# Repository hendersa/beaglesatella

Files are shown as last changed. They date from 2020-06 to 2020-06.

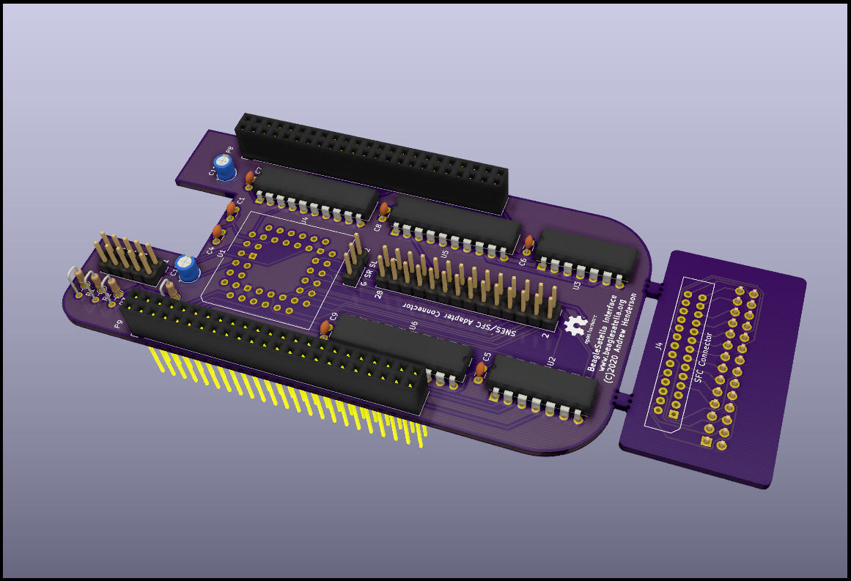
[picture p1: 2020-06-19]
images/beaglesatella_cape.jpg

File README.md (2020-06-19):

** SUMMARY **
BeagleSatella is a hardware/software solution that implements the basic 
interface functions of peripherals compatible with the Super Nintendo (SNES)
and Super Famicom (SFC) game consoles. These consoles contain a rarely-used
expansion port on their underside that was intended to interface with a variety
of hardware peripherals. Unfortunately, very few commercial peripherals were 
made available, with the most widely used being the Japan-only Satellaview 
satellite modem. 

BeagleSatella is not emulation, but an actual SNES add-on peripheral that plugs
directly into your game console. BeagleSatella uses a BeagleBone Black (BBB) 
single-board computer with a custom "cape" expansion PCB as the hardware to 
interface with the console. Firmware running on the BBB's pair of programmable
real-time units (PRUs) provides the nanosecond-scale timing required to
interface with the SNES in real-time. Additional peripheral behaviors are 
controlled using kernel drivers and userspace software running under the BBB's
Linux OS. 

** AUTHOR **
Andrew Henderson (hendersa@icculus.org): https://icculus.org/~hendersa

** DESCRIPTION **
The BeagleSatella hardware and firmware offers the following features:

- CPLD-based Hardware filtering and translation of memory-mapped I/O register
accesses from the SNES B-Bus.

- Integrated JTAG interface for easy CPLD reprogramming.

- Arbitrary range of up to 64 contiguous memory-mapped I/O registers available.

- BBB PRU usage guarantees the servicing of register read/write requests within
a 150 ns time window.

- Audio interfacing via the expansion port's stereo audio inputs.

** BUILDING **
Since BeagleSatella has both hardware and software aspects to it, this 
repository is broken down into several subdirectories:

- "cpld" contains the CUPL source code for the CPLD IC used on the cape PCB.

- "firmware" contains the PRU firmware for the BBB that communicates with the
cape PCB.

- "images" contains schematics, board renders, and other images that provide a 
preview of the system.

- "kernel" contains the kernel driver and device tree files for the BBB so that 
the BBB can communicate with the cape PCB.

- "pcb" contains the KiCad design files and gerber files for the cape PCB.

- "userspace" contains BBB userspace software for high-level control of the
whole BeagleSatella system.

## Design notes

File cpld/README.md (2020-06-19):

** SUMMARY **
The BeagleSatella hardware uses a CPLD that acts as a filter on the SNES B-Bus.
In short, there is a lot of B-Bus traffic, but BeagleSatella is only interested
in bus reads/writes that map to one of its MMIO registers. Rather than 
determine in software whether an address on the B-Bus is intended for 
BeagleSatella, the CPLD evaluates all addresses on the bus in hardware and then
only passes along the appropriate read/write control signals if the address
matches a BeagleSatella MMIO register. Because this is implemented in hardware,
the comparison can be made in ~20ns.

You shouldn't need to change the BeagleSatella CPLD design unless you are 
modifying it to filter a different range of MMIO addresses for your own 
project. You will need to program the CPLD is you are building your own
hardware from scratch and need to do the initial programming of the CPLD.

** AUTHOR **
Andrew Henderson (hendersa@icculus.org): https://icculus.org/~hendersa

** DESCRIPTION/BUILDING **
The CPLD used in BeagleSatella is an Atmel ATF1504AS in a PLCC package. The
tools and toolchain for synthesizing and programming a design for this CPLD are
Windows-based, free, and downloadable from here:

https://www.microchip.com/design-centers/fpgas-and-plds/splds-cplds/pld-design-resources 

The software tools you need are WinCUPL (for compiling the CUPL design source
code) and ATMISP (for programming the CPLD via JTAG).  You’ll also need a 
hardware JTAG programmer that uses a JTAG-A 10-pin connector. I use the 
Microchip ATDH1150USB USB ISP cable, which costs rough 60USD. The workflow is
as follows:

1. Using WinCUPL, open the file BEAGLESATELLA.pld. This is the main source 
file. Click the “Device Dependent Compile” button on the WinCUPL GUI to compile
this design and generate a variety of intermediary files. The two generated 
files of interest are the BEAGLESATELLA.jed JEDEC file (the file to be 
programmed to the CPLD) and the BEAGLESATELLA.fit file (the pinout and logic 
summary).

2. If you are serious about CPLD development and want to really experiment with
BeagleSatella’s CPLD source, you should have a CPLD development kit:

- ATF15XX-DK3-U CPLD development kit, with JTAG USB cable (~160USD)
- ATF15XXDK3-SAJ44 44-pin PLCC adapter for the devkit (~40USD)

If you are only interested in tweaking the CPLD design and reprogramming your
CPLD, BeagleSatella supports in-system programming (ISP). In short, you can 
connect a JTAG cable that supports JTAG-A (10-pin) to the BeagleSatella 
(connector J3) and program the CPLD in-place. For this, you’ll only need a JTAG
USB cable:

- ATDH1150USB USB JTAG cable (~60USD)

This USB JTAG cable is included in the ATF15XX development kit. The kit's docs
say that it comes with a parallel port-based JTAG cable, but this isn't the
case. Once you have the appropriate equipment, it is time to start programming
the CPLD.

3. Ensure that you have the CPLD powered up and is ready to be programmed. When
using the dev kit, the programming process is:

A. Power down the dev kit
B. Change the “VccIO Selector” jumper to “5V(AS)”
C. CAREFULLY insert the 44-pin PLCC into the PLCC adapter (the adapter pins 
bend very easily)
D. Power up the dev kit
E. Program the CPLD using ATMISP
F. Power down the dev kit
G. Power down your BBB
G. Remove the CPLD from the dev kit and place it into the U1 socket on the
BeagleSatella (the “dot” for pin 1 should face the BBB’s ethernet jack)
H. Power up your BBB

When programming the CPLD using the BeagleSatella board, the programming
process is:

A. Power up your BBB
B. Connect the USB JTAG cable to connector J3 of the BeagleSatella
C. Program the CPLD using ATMISP
D. Disconnect the USB JTAG cable from connector J3 

4. Now that you have the JEDEC file, use ATMISP to program the CPLD with the
compiled design. Connect to the USB JTAG to both the system with the CPLD 
(either BeagleSatella or the CPLD dev kit) and your desktop PC. Read the 
ATMISP documentation for the details, but the workflow is:

A. Add the ATF1504AS to the JTAG scan chain (Edit → Add New Device)
B. “Erase” the CPLD
C. “Program/Verify” the CPLD using the JEDEC file “BEAGLESATELLA.jed”

Additional Notes:

- WinCUPL can’t handle spaces in filenames, so don’t try to build your project
from some directory named something like “c:\my stuff\beaglesatella”. It will
just fail without an explanation.
- WinCUPL crashes a lot, so save often!
- When making design changes, WinCUPL can silently fail at an intermediary 
stage of the compilation process. It doesn’t remove any existing output files
when it does this, so it may look like your compile has completed successfully.
I highly recommend you manually delete all files except the .pld and .si files
before you rebuild the project.
- If WinCUPL is silently failing to build your project, and you've gotten far
enough to generate the BEAGLESATELLA.tt2 file, try running the included 
"build.bat" file. This executes the fitter program for the ATF1504 CPLD and
dumps out build errors that the WinCUPL GUI never shows you.

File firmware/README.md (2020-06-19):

** SUMMARY ** 
This directory contains both the current in-development PRU firmware and 
a test program to load the firmware onto the PRUs using the UIO driver.

** AUTHOR **
Andrew Henderson (hendersa@icculus.org): https://icculus.org/~hendersa

** DESCRIPTION **
The key files in this repository are:

prussdrv/*   : The Texas Instruments prussdrv driver library
pru.c        : Convenience wrapper functions around the prussdrv interface
test.c       : Starts execution of PRU firmware
pru0.p       : PRU0 firmware code (PRU assembly)
pru1.p       : PRU1 firmware code (PRU assembly)

** BUILDING **
To build the *.p files, you'll need the PASM tool:

$ git clone https://github.com/beagleboard/am335x_pru_package
$ cd am335x_pru_package/pru_sw/utils/pasm_source
$ ./linuxbuild
$ sudo cp ../pasm /usr/local/bin

Once PASM is installed, you can build the software (on your BBB) via make:

$ make

Then, load the firmware onto the PRUs and start them running:

$ sudo ./test

Since the PRU code uses every available PRU signal, the BeagleSatella device
tree overlay in the "kernel" directory must be used prior to running the PRU
code. This also means that the eMMC and HDMI overlays must be disabled in your
uEnv.txt file.

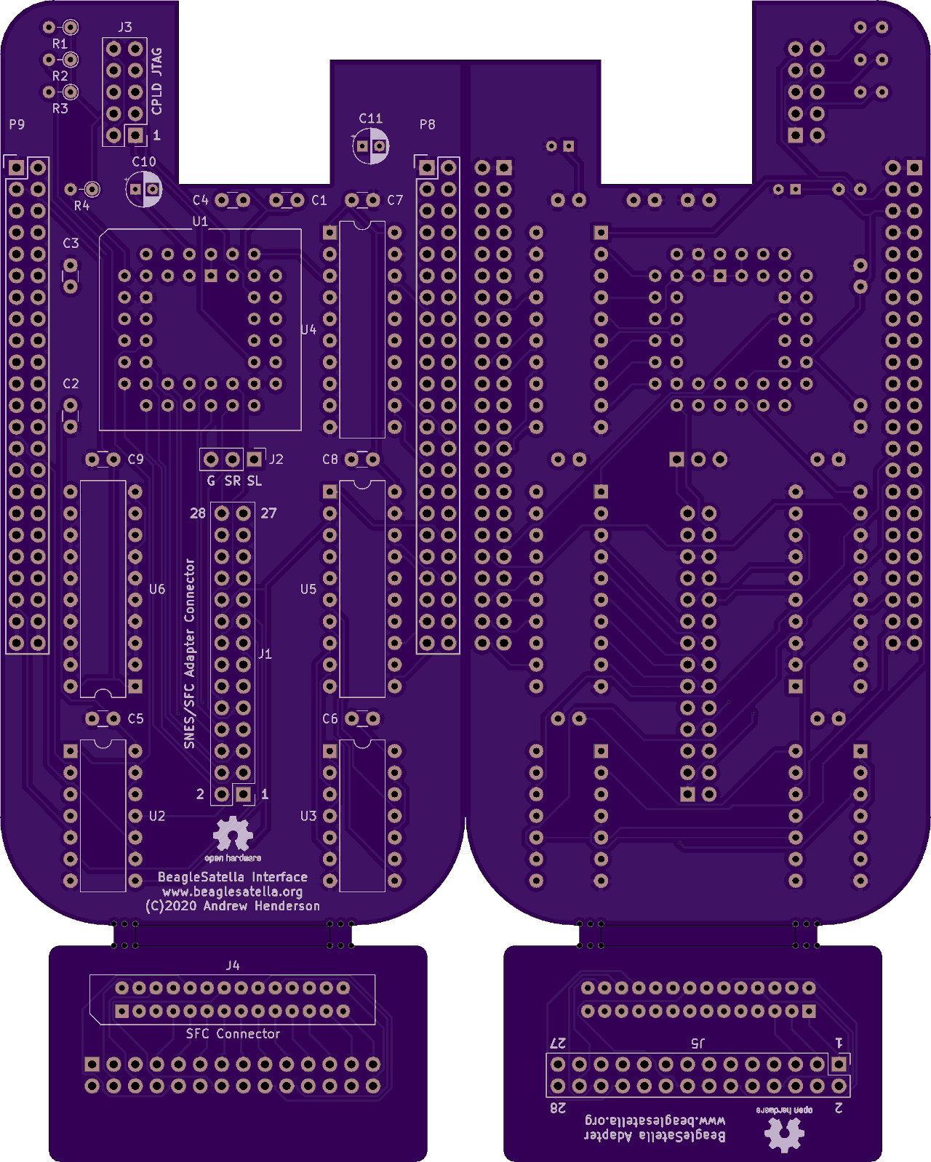
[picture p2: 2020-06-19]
images/PCB_preview.jpg

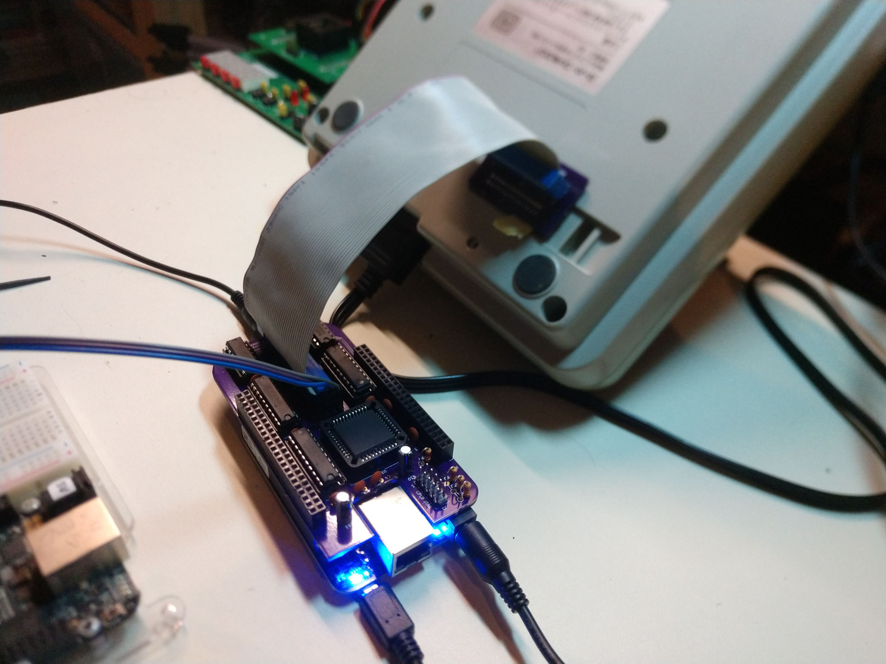
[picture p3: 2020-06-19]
images/in_use.jpg

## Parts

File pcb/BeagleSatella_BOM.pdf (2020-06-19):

# Bill Of Materials For BeagleSatella Interface Cape Board

Qty | Value | Parts | Package | Digikey Part | Unit Price | Extended Price | Description | Additional Notes
2 1 1 1 4 9 2 1 1 2 3 2 | N/A N/A N/A N/A 10k 0.1uF 10uF N/A N/A N/A N/A N/A | J1, J5 J2 J3 J4 R1-R4 C1-C9 C10-C11 N/A U1 U2, U3 U4-U6 P8, P9 | N/A N/A N/A N/A Axial ¼ Watt Ceramic Radial Aluminum Radial 44-pin PLCC 44-pin PLCC 14-Pin DIP 20-Pin DIP N/A | S2021EC-14-ND S1012EC-03-ND 1849-1002-ND 612-MEC2-40-01-L-TH1-WT-ND 10KQBK-ND BC5137-ND P15786CT-ND 123-A-CCS044-Z-T-ND ATF1504AS-10JU44-ND 296-4655-5-ND 296-8503-5-ND S2012EC-23-ND | $0.79 $0.09 $0.16 $0.02 $0.10 $0.16 $0.24 $1.17 $3.20 $0.40 $0.59 $0.79 | $1.58 $0.09 $0.16 $0.02 $0.40 $1.47 $0.48 $1.17 $3.20 $0.80 $1.77 $1.58 | Connection Header Vertical 28 Pos 2.54mm Pitch Connection Header Vertical 3 Pos 2.54mm Pitch Connection Header Vertical 10 Pos 2.54mm Pitch Connector Card Edge 2mm Vertical Resistor 10K Ohm 1/4W 5% Axial Capacitor Ceramic 0.1uF 50V X7R Radial Capacitor Aluminum 10uF 20% 16V Radial Connector Socket PLCC 44 Pos Tin Atmel ATF1504AS 10ns CPLD SN74AHCT125N IC Buffer Non-Interting 5.5V SN74LVC245AN IC TXRX Non-Inverting 3.6V Connection Header Vertical 46 Pos 2.54mm Pitch | Must be cut to 2x18, provides 2 connectors Priced at per-unit cost of 10-unit price break Socket for U1 Beaglebone cape header, 2x23 pins
Total: | 12.715

# Alternative Components

Qty | Value | Parts | Package | Digikey Part | Unit Price | Extended Price | Description | Additional Notes
1 | N/A | P8,P9 | N/A | 1528-1365-ND | $4.95 | $4.95 | Header Stack BeagleBone (2 piece) | Pair of Beaglebone cape headers (pass-through)

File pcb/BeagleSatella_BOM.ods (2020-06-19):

Bill Of Materials For BeagleSatella Interface Cape Board
Qty | Value | Parts | Package | Digikey Part | Unit Price | Extended Price | Description | Additional Notes
2 | N/A | J1, J5 | N/A | S2021EC-14-ND | $0.79 | $1.58 | Connection Header Vertical 28 Pos 2.54mm Pitch
1 | N/A | J2 | N/A | S1012EC-03-ND | $0.09 | $0.09 | Connection Header Vertical 3 Pos 2.54mm Pitch
1 | N/A | J3 | N/A | 1849-1002-ND | $0.16 | $0.16 | Connection Header Vertical 10 Pos 2.54mm Pitch
1 | N/A | J4 | N/A | 612-MEC2-40-01-L-TH1-WT-ND | $0.02 | $0.02 | Connector Card Edge 2mm Vertical | Must be cut to 2x18, provides 2 connectors
4 | 10k | R1-R4 | Axial ¼ Watt | 10KQBK-ND | $0.10 | $0.40 | Resistor 10K Ohm 1/4W 5% Axial
9 | 0.1uF | C1-C9 | Ceramic Radial | BC5137-ND | $0.16 | $1.47 | Capacitor Ceramic 0.1uF 50V X7R Radial | Priced at per-unit cost of 10-unit price break
2 | 10uF | C10-C11 | Aluminum Radial | P15786CT-ND | $0.24 | $0.48 | Capacitor Aluminum 10uF 20% 16V Radial
1 | N/A | N/A | 44-pin PLCC | 123-A-CCS044-Z-T-ND | $1.17 | $1.17 | Connector Socket PLCC 44 Pos Tin | Socket for U1
1 | N/A | U1 | 44-pin PLCC | ATF1504AS-10JU44-ND | $3.20 | $3.20 | Atmel ATF1504AS 10ns CPLD
2 | N/A | U2, U3 | 14-Pin DIP | 296-4655-5-ND | $0.40 | $0.80 | SN74AHCT125N IC Buffer Non-Interting 5.5V
3 | N/A | U4-U6 | 20-Pin DIP | 296-8503-5-ND | $0.59 | $1.77 | SN74LVC245AN IC TXRX Non-Inverting 3.6V
2 | N/A | P8, P9 | N/A | S2012EC-23-ND | $0.79 | $1.58 | Connection Header Vertical 46 Pos 2.54mm Pitch | Beaglebone cape header, 2x23 pins
 |  |  |  | Total: |  | 12.715
Alternative Components
Qty | Value | Parts | Package | Digikey Part | Unit Price | Extended Price | Description | Additional Notes
1 | N/A | P8,P9 | N/A | 1528-1365-ND | $4.95 | $4.95 | Header Stack BeagleBone (2 piece) | Pair of Beaglebone cape headers (pass-through)

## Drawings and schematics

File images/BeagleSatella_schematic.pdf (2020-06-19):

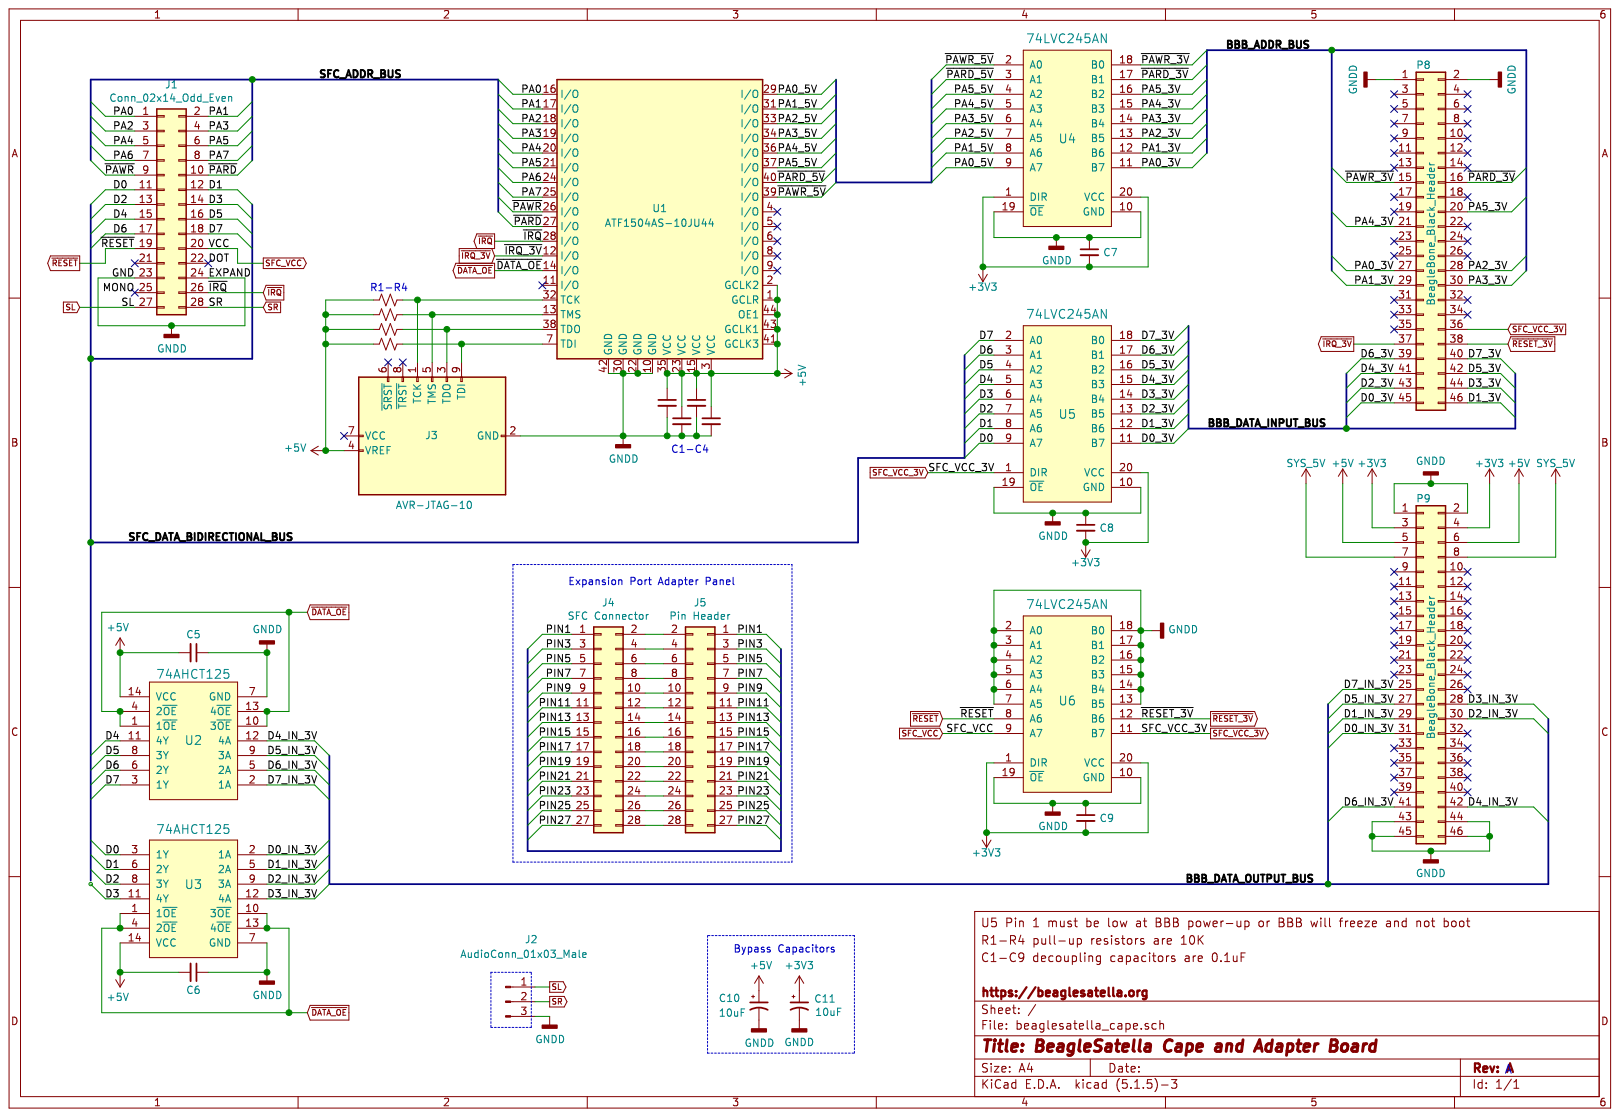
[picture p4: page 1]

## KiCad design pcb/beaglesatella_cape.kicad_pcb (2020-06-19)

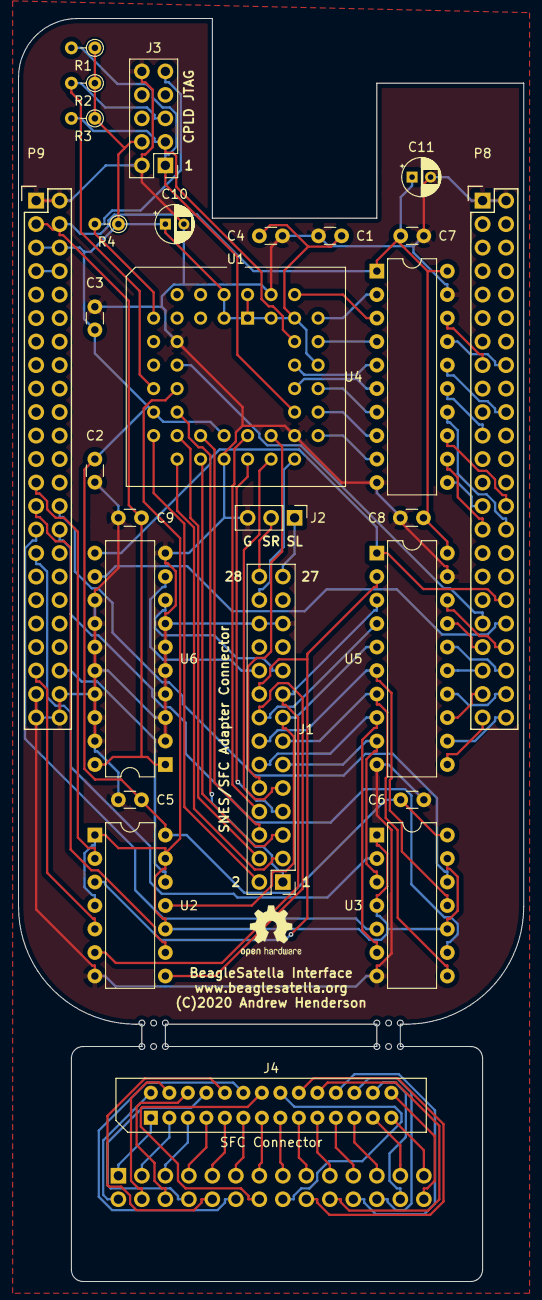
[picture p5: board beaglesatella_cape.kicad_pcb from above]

Board: 2 copper layers, 54.6 x 136.5 mm, 40 parts (1 on the bottom side), 95 nets.

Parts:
 : Panel_Tab_Hole
 #2,  #3,  #4,  #5,  #6,  #7,  #8,  #9,  #10,  #11,  #12: Panel_Tab_Hole
C1, C2, C3, C4, C5, C6, C7, C8, C9: 0.1uF; C_Disc_D3.0mm_W1.6mm_P2.50mm
C10, C11: 10uF; CP_Radial_D4.0mm_P2.00mm
J1: Conn_02x14_Odd_Even; PinHeader_2x14_P2.54mm_Vertical
J2: AudioConn_01x03_Male; PinHeader_1x03_P2.54mm_Vertical
J3: AVR-JTAG-10; PinHeader_2x05_P2.54mm_Vertical
J4: SFC Connector; Samtec_MECF-40-01-L-DV-WT_2x40_P1.27mm_Polarized_Socket_Hor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
J5: Pin Header; PinHeader_2x14_P2.54mm_Vertical
P8, P9: BeagleBone_Black_Header; Socket_BeagleBone_Black
R1, R2, R3, R4: 10K; R_Axial_DIN0204_L3.6mm_D1.6mm_P2.54mm_Vertical
U1: ATF1504AS-10JU44; PLCC-44_THT-Socket
U2, U3: 74AHCT125; DIP-14_W7.62mm
U4, U5, U6: 74LVC245AN; DIP-20_W7.62mm

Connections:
+3V3: C7.2, C8.2, C9.2, C11.1, P9.3, P9.4, U4.1, U4.20, U5.20, U6.1, U6.20
+5V: C1.1, C2.1, C3.1, C4.1, C5.2, C6.2, C10.1, J3.4, P9.5, P9.6, R1.1, R2.1, R3.1, R4.1, U1.1, U1.2, U1.3, U1.15, U1.23, U1.35, U1.41, U1.43, U1.44, U2.14, U3.14
/D0: J1.11, U3.3, U5.9
/D0_3V: P8.45, U5.11
/D0_IN_3V: P9.31, U3.2
/D1: J1.12, U3.6, U5.8
/D1_3V: P8.46, U5.12
/D1_IN_3V: P9.29, U3.5
/D2: J1.13, U3.8, U5.7
/D2_3V: P8.43, U5.13
/D2_IN_3V: P9.30, U3.9
/D3: J1.14, U3.11, U5.6
/D3_3V: P8.44, U5.14
/D3_IN_3V: P9.28, U3.12
/D4: J1.15, U2.11, U5.5
/D4_3V: P8.41, U5.15
/D4_IN_3V: P9.42, U2.12
/D5: J1.16, U2.8, U5.4
/D5_3V: P8.42, U5.16
/D5_IN_3V: P9.27, U2.9
/D6: J1.17, U2.6, U5.3
/D6_3V: P8.39, U5.17
/D6_IN_3V: P9.41, U2.5
/D7: J1.18, U2.3, U5.2
/D7_3V: P8.40, U5.18
/D7_IN_3V: P9.25, U2.2
/PA0: J1.1, U1.16
/PA0_3V: P8.27, U4.11
/PA0_5V: U1.29, U4.9
/PA1: J1.2, U1.17
/PA1_3V: P8.29, U4.12
/PA1_5V: U1.31, U4.8
/PA2: J1.3, U1.18
/PA2_3V: P8.28, U4.13
/PA2_5V: U1.33, U4.7
/PA3: J1.4, U1.19
/PA3_3V: P8.30, U4.14
/PA3_5V: U1.34, U4.6
/PA4: J1.5, U1.20
/PA4_3V: P8.21, U4.15
/PA4_5V: U1.36, U4.5
/PA5: J1.6, U1.21
/PA5_3V: P8.20, U4.16
/PA5_5V: U1.37, U4.4
/PA6: J1.7, U1.24
/PA7: J1.8, U1.25
/PIN1: J4.1, J5.1
/PIN3: J4.3, J5.3
/PIN5: J4.5, J5.5
/PIN7: J4.7, J5.7
/PIN9: J4.9, J5.9
/PIN11: J4.11, J5.11
/PIN13: J4.13, J5.13
/PIN15: J4.15, J5.15
/PIN17: J4.17, J5.17
/PIN19: J4.19, J5.19
/PIN21: J4.21, J5.21
/PIN23: J4.23, J5.23
/PIN25: J4.25, J5.25
/PIN27: J4.27, J5.27
/~PARD: J1.10, U1.27
/~PARD_3V: P8.16, U4.17
/~PARD_5V: U1.40, U4.3
/~PAWR: J1.9, U1.26
/~PAWR_3V: P8.15, U4.18
/~PAWR_5V: U1.39, U4.2
GNDD: C1.2, C2.2, C3.2, C4.2, C5.1, C6.1, C7.1, C8.1, C9.1, C10.2, C11.2, J1.23, J1.24, J2.3, J3.2, J3.10, P8.1, P8.2, P9.1, P9.2, P9.43, P9.44, P9.45, P9.46, U1.10, U1.22, U1.30, U1.42, U2.7, U3.7, U4.10, U4.19, U5.10, U5.19, U6.2, U6.3, U6.4, U6.5, U6.6, U6.7, U6.10, U6.13, U6.14, U6.15, U6.16, U6.17, U6.18, U6.19
unnamed: J3.1, R1.2, U1.32
unnamed: J3.3, R3.2, U1.38
unnamed: J3.5, R2.2, U1.13
unnamed: J3.9, R4.2, U1.7
unnamed: J4.2, J5.2
unnamed: J4.4, J5.4
unnamed: J4.6, J5.6
unnamed: J4.8, J5.8
unnamed: J4.10, J5.10
unnamed: J4.12, J5.12
unnamed: J4.14, J5.14
unnamed: J4.16, J5.16
unnamed: J4.18, J5.18
unnamed: J4.20, J5.20
unnamed: J4.22, J5.22
unnamed: J4.24, J5.24
unnamed: J4.26, J5.26
unnamed: J4.28, J5.28
SFC_VCC: J1.20, U6.9
SFC_VCC_3V: P8.36, U5.1, U6.11
SL: J1.27, J2.1
SR: J1.28, J2.2
SYS_5V: P9.7, P9.8
~DATA_OE: U1.14, U2.1, U2.4, U2.10, U2.13, U3.1, U3.4, U3.10, U3.13
~IRQ: J1.26, U1.28
~IRQ_3V: P8.37, U1.12
~RESET: J1.19, U6.8
~RESET_3V: P8.38, U6.12

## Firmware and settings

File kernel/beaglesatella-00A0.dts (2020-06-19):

/*
 * Copyright (C) 2020 Andrew Henderson (hendersa@icculus.org)
 *
 * This program is free software; you can redistribute it and/or modify
 * it under the terms of the GNU General Public License version 2 as
 * published by the Free Software Foundation.
 */
/dts-v1/;
/plugin/;

/ {
	compatible = "ti,beaglebone-black";

	/* identification */
	part-number = "BEAGLESATELLA";
	version = "00A0";

	fragment@0 {
		target-path="/";
		__overlay__ {
			pru-beaglesatella {
				compatible = "beaglesatella,beaglesatella";
				pruss = <&pruss>;
				interrupt-parent = <&pruss_intc>;
				interrupts = <22>, <23>, <24>;
				interrupt-names = "from_bl_1", "to_bl", "from_bl_2";
			};
		};
	};

	/*
	 * Free up the pins used by the cape from the pinmux helpers.
	 */
	fragment@1 {
		target = <&ocp>;
		__overlay__ {

			/* PRU0 R30 DataOut[7:0] pins (Mode 5, Output) */
			P9_31_pinmux { status = "disabled"; };  /* P9_31:   R30[0] -> DataOut[0] */
			P9_29_pinmux { status = "disabled"; };  /* P9_29:   R30[1] -> DataOut[1] */ 
			P9_30_pinmux { status = "disabled"; };  /* P9_30:   R30[2] -> DataOut[2] */
			P9_28_pinmux { status = "disabled"; };  /* P9_28:   R30[3] -> DataOut[3] */
			P9_92_pinmux { status = "disabled"; };	/* P9_42.1: R30[4] -> DataOut[4] */
			P9_27_pinmux { status = "disabled"; };	/* P9_27:   R30[5] -> DataOut[5] */
			P9_91_pinmux { status = "disabled"; };  /* P9_41.1: R30[6] -> DataOut[6] */
			P9_25_pinmux { status = "disabled"; };	/* P9_25:   R30[7] -> DataOut[7] */

			/* Eliminate P9_41/42 conflicts (Mode 7, Input) */
			P9_41_pinmux { status = "disabled"; };
			P9_42_pinmux { status = "disabled"; };

			/* PRU0 R31 PARD input pin (Mode 6, Input) */
			P8_16_pinmux { status = "disabled"; };	/* P8_16: PARD -> R31[14] */

			/* PRU0 R31 PAWR input pin (Mode 6, Input) */
			P8_15_pinmux { status = "disabled"; };	/* P8_15: PAWR -> R31[15] */

			/* PRU1 R31 DataIn[7:0] pins (Mode 6, Input) */
			P8_45_pinmux { status = "disabled"; };	/* P8_45: DataIn[0] -> R31[0] */
			P8_46_pinmux { status = "disabled"; };	/* P8_46: DataIn[1] -> R31[1] */
			P8_43_pinmux { status = "disabled"; };	/* P8_43: DataIn[2] -> R31[2] */
			P8_44_pinmux { status = "disabled"; };	/* P8_44: DataIn[3] -> R31[3] */
			P8_41_pinmux { status = "disabled"; };	/* P8_41: DataIn[4] -> R31[4] */
			P8_42_pinmux { status = "disabled"; };	/* P8_42: DataIn[5] -> R31[5] */
			P8_39_pinmux { status = "disabled"; };	/* P8_39: DataIn[6] -> R31[6] */
			P8_40_pinmux { status = "disabled"; };  /* P8_40: DataIn[7] -> R31[7] */

			/* PRU1 R31 AddrIn[5:0] pins (Mode 6, Input) */
			P8_27_pinmux { status = "disabled"; };  /* P8_27: AddrIn[0] -> R31[8] */
			P8_29_pinmux { status = "disabled"; };  /* P8_29: AddrIn[1] -> R31[9] */
			P8_28_pinmux { status = "disabled"; };  /* P8_28: AddrIn[2] -> R31[10] */
			P8_30_pinmux { status = "disabled"; };  /* P8_30: AddrIn[3] -> R31[11] */
			P8_21_pinmux { status = "disabled"; };  /* P8_21: AddrIn[4] -> R31[12] */
			P8_20_pinmux { status = "disabled"; };	/* P8_20: AddrIn[5] -> R31[13] */

			/* KERNEL GPIO /RESET pin (Mode 7, Input) */
			P8_38_pinmux { status = "disabled"; };  /* P8_38: /RESET -> GPIO2[15] */

			/* KERNEL GPIO /IRQ pin (Mode 7, Output) */
			P8_37_pinmux { status = "disabled"; };  /* P8_37: GPIO2[14] -> /IRQ */

			/* KERNEL GPIO VCC pin (Mode 7, Input) */
			P8_36_pinmux { status = "disabled"; };	/* P8_36: VCC -> GPIO2[16] */

			beaglesatella_helper: helper {
				compatible = "bone-pinmux-helper";
				pinctrl-names = "default";
				pinctrl-0 = <&beaglesatella_pins>;
				status = "okay";
			};
		};
	};

	fragment@2 {
		target = <&am33xx_pinmux>;
		__overlay__ {
			beaglesatella_pins: beaglesatella_pins {
				pinctrl-single,pins = <
					/* PRU0 R30 DataOut_3V[7:0] pins (Mode 5: PRU Output) */
					0x190 0x25	/* P9_31 */
					0x194 0x25	/* P9_29 */
					0x198 0x25	/* P9_30 */
					0x19c 0x25	/* P9_28 */
					0x1a0 0x25	/* P9_42.1 */
					0x1a4 0x25	/* P9_27 */
					0x1a8 0x25	/* P9_41.1 */
					0x1ac 0x25	/* P9_25 */

					/* Eliminate P9_41/42 conflicts (Mode 7: GPIO, Input, Disabled Pull-Up/Down, Fast Slew: 0x2F) */
					0x1b4 0x2F	/* P9_41 */
					0x164 0x2F	/* P9_42 */

					/* PRU0 R31 /PARD_3V pin (Mode 6: PRU Input) */
					0x038 0x26	/* P8_16 */

					/* PRU0 R31 /PAWR_3V pin (Mode 6: PRU Input) */
					0x03c 0x26	/* P8_15 */

					/* PRU1 R31 DataIn_3V[7:0] pins (Mode 6: PRU Input) */
					0x0a0 0x26	/* P8_45 */
					0x0a4 0x26	/* P8_46 */
					0x0a8 0x26	/* P8_43 */
					0x0ac 0x26	/* P8_44 */
					0x0b0 0x26	/* P8_41 */
					0x0b4 0x26	/* P8_42 */
					0x0b8 0x26	/* P8_39 */
					0x0bc 0x26	/* P8_40 */

					/* PRU1 R31 AddrIn[5:0] pins (Mode 6: PRU Input) */
					0x0e0 0x26	/* P8_27 */
					0x0e4 0x26	/* P8_29 */
					0x0e8 0x26	/* P8_28 */
					0x0ec 0x26	/* P8_30 */
					0x080 0x26	/* P8_21 */
					0x084 0x26	/* P8_20 */

					/* KERNEL GPIO /RESET_3V pin (Mode 7: GPIO, Input, Pull Up, Fast Slew: 0x37) */
					0x0c4 0x37	/* P8_38 */ 

					/* KERNEL GPIO /IRQ_3V pin (Mode 7: GPIO, Output, Disabled Pull Up/Down, Fast Slew: 0x0F) */
					0x0c0 0x0F	/* P8_37 */ 

					/* KERNEL GPIO SFC_VCC_3V pin (Mode 7: GPIO, Input, Pull Down, Fast Slew: 0x27) */
					0x0c8 0x27	/* P8_36 */

				>;
			};
		};
	};

};

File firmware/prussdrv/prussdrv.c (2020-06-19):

/*
 * prussdrv.c
 *
 * User space driver for PRUSS
 *
 * Copyright (C) 2012 Texas Instruments Incorporated - http://www.ti.com/
 *
 *
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
 *    Redistributions of source code must retain the above copyright
 *    notice, this list of conditions and the following disclaimer.
 *
 *    Redistributions in binary form must reproduce the above copyright
 *    notice, this list of conditions and the following disclaimer in the
 *    documentation and/or other materials provided with the
 *    distribution.
 *
 *    Neither the name of Texas Instruments Incorporated nor the names of
 *    its contributors may be used to endorse or promote products derived
 *    from this software without specific prior written permission.
 *
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
*/


/*
 * ============================================================================
 * Copyright (c) Texas Instruments Inc 2010-12
 *
 * Use of this software is controlled by the terms and conditions found in the
 * license agreement under which this software has been supplied or provided.
 * ============================================================================
 */

#include "prussdrv.h"
#include "__prussdrv.h"
#include <stdio.h>

#ifdef __DEBUG
#define DEBUG_PRINTF(FORMAT, ...) fprintf(stderr, FORMAT, ## __VA_ARGS__)
#else
#define DEBUG_PRINTF(FORMAT, ...)
#endif

#define PRUSS_UIO_PRAM_PATH_LEN 128
#define PRUSS_UIO_PARAM_VAL_LEN 20
#define HEXA_DECIMAL_BASE 16

static tprussdrv prussdrv;

int __prussdrv_memmap_init(void)
{
    int i, fd;
    char hexstring[PRUSS_UIO_PARAM_VAL_LEN];

    if (prussdrv.mmap_fd == 0) {
        for (i = 0; i < NUM_PRU_HOSTIRQS; i++) {
            if (prussdrv.fd[i])
                break;
        }
        if (i == NUM_PRU_HOSTIRQS)
            return -1;
        else
            prussdrv.mmap_fd = prussdrv.fd[i];
    }
    fd = open(PRUSS_UIO_DRV_PRUSS_BASE, O_RDONLY);
    if (fd >= 0) {
        read(fd, hexstring, PRUSS_UIO_PARAM_VAL_LEN);
        prussdrv.pruss_phys_base =
            strtoul(hexstring, NULL, HEXA_DECIMAL_BASE);
        close(fd);
    } else
        return -1;
    fd = open(PRUSS_UIO_DRV_PRUSS_SIZE, O_RDONLY);
    if (fd >= 0) {
        read(fd, hexstring, PRUSS_UIO_PARAM_VAL_LEN);
        prussdrv.pruss_map_size =
            strtoul(hexstring, NULL, HEXA_DECIMAL_BASE);
        close(fd);
    } else
        return -1;

    prussdrv.pru0_dataram_base =
        mmap(0, prussdrv.pruss_map_size, PROT_READ | PROT_WRITE,
             MAP_SHARED, prussdrv.mmap_fd, PRUSS_UIO_MAP_OFFSET_PRUSS);
    prussdrv.version =
        __pruss_detect_hw_version((uint32_t *)prussdrv.pru0_dataram_base);

    switch (prussdrv.version) {
    case PRUSS_V1:
        {
            DEBUG_PRINTF(PRUSS_V1_STR "\n");
            prussdrv.pru0_dataram_phy_base = AM18XX_DATARAM0_PHYS_BASE;
            prussdrv.pru1_dataram_phy_base = AM18XX_DATARAM1_PHYS_BASE;
            prussdrv.intc_phy_base = AM18XX_INTC_PHYS_BASE;
            prussdrv.pru0_control_phy_base = AM18XX_PRU0CONTROL_PHYS_BASE;
            prussdrv.pru0_debug_phy_base = AM18XX_PRU0DEBUG_PHYS_BASE;
            prussdrv.pru1_control_phy_base = AM18XX_PRU1CONTROL_PHYS_BASE;
            prussdrv.pru1_debug_phy_base = AM18XX_PRU1DEBUG_PHYS_BASE;
            prussdrv.pru0_iram_phy_base = AM18XX_PRU0IRAM_PHYS_BASE;
            prussdrv.pru1_iram_phy_base = AM18XX_PRU1IRAM_PHYS_BASE;
        }
        break;
    case PRUSS_V2:
        {
            DEBUG_PRINTF(PRUSS_V2_STR "\n");
            prussdrv.pru0_dataram_phy_base = AM33XX_DATARAM0_PHYS_BASE;
            prussdrv.pru1_dataram_phy_base = AM33XX_DATARAM1_PHYS_BASE;
            prussdrv.intc_phy_base = AM33XX_INTC_PHYS_BASE;
            prussdrv.pru0_control_phy_base = AM33XX_PRU0CONTROL_PHYS_BASE;
            prussdrv.pru0_debug_phy_base = AM33XX_PRU0DEBUG_PHYS_BASE;
            prussdrv.pru1_control_phy_base = AM33XX_PRU1CONTROL_PHYS_BASE;
            prussdrv.pru1_debug_phy_base = AM33XX_PRU1DEBUG_PHYS_BASE;
            prussdrv.pru0_iram_phy_base = AM33XX_PRU0IRAM_PHYS_BASE;
            prussdrv.pru1_iram_phy_base = AM33XX_PRU1IRAM_PHYS_BASE;
            prussdrv.pruss_sharedram_phy_base =
                AM33XX_PRUSS_SHAREDRAM_BASE;
            prussdrv.pruss_cfg_phy_base = AM33XX_PRUSS_CFG_BASE;
            prussdrv.pruss_uart_phy_base = AM33XX_PRUSS_UART_BASE;
            prussdrv.pruss_iep_phy_base = AM33XX_PRUSS_IEP_BASE;
            prussdrv.pruss_ecap_phy_base = AM33XX_PRUSS_ECAP_BASE;
            prussdrv.pruss_miirt_phy_base = AM33XX_PRUSS_MIIRT_BASE;
            prussdrv.pruss_mdio_phy_base = AM33XX_PRUSS_MDIO_BASE;
        }
        break;
    default:
        DEBUG_PRINTF(PRUSS_UNKNOWN_STR "\n");
    }

    prussdrv.pru1_dataram_base =
        prussdrv.pru0_dataram_base + prussdrv.pru1_dataram_phy_base -
        prussdrv.pru0_dataram_phy_base;
    prussdrv.intc_base =
        prussdrv.pru0_dataram_base + prussdrv.intc_phy_base -
        prussdrv.pru0_dataram_phy_base;
    prussdrv.pru0_control_base =
        prussdrv.pru0_dataram_base + prussdrv.pru0_control_phy_base -
        prussdrv.pru0_dataram_phy_base;
    prussdrv.pru0_debug_base =
        prussdrv.pru0_dataram_base + prussdrv.pru0_debug_phy_base -
        prussdrv.pru0_dataram_phy_base;
    prussdrv.pru1_control_base =
        prussdrv.pru0_dataram_base + prussdrv.pru1_control_phy_base -
        prussdrv.pru0_dataram_phy_base;
    prussdrv.pru1_debug_base =
        prussdrv.pru0_dataram_base + prussdrv.pru1_debug_phy_base -
        prussdrv.pru0_dataram_phy_base;
    prussdrv.pru0_iram_base =
        prussdrv.pru0_dataram_base + prussdrv.pru0_iram_phy_base -
        prussdrv.pru0_dataram_phy_base;
    prussdrv.pru1_iram_base =
        prussdrv.pru0_dataram_base + prussdrv.pru1_iram_phy_base -
        prussdrv.pru0_dataram_phy_base;
    if (prussdrv.version == PRUSS_V2) {
        prussdrv.pruss_sharedram_base =
            prussdrv.pru0_dataram_base +
            prussdrv.pruss_sharedram_phy_base -
            prussdrv.pru0_dataram_phy_base;
        prussdrv.pruss_cfg_base =
            prussdrv.pru0_dataram_base + prussdrv.pruss_cfg_phy_base -
            prussdrv.pru0_dataram_phy_base;
        prussdrv.pruss_uart_base =
            prussdrv.pru0_dataram_base + prussdrv.pruss_uart_phy_base -
            prussdrv.pru0_dataram_phy_base;
        prussdrv.pruss_iep_base =
            prussdrv.pru0_dataram_base + prussdrv.pruss_iep_phy_base -
            prussdrv.pru0_dataram_phy_base;
        prussdrv.pruss_ecap_base =
            prussdrv.pru0_dataram_base + prussdrv.pruss_ecap_phy_base -
            prussdrv.pru0_dataram_phy_base;
        prussdrv.pruss_miirt_base =
            prussdrv.pru0_dataram_base + prussdrv.pruss_miirt_phy_base -
            prussdrv.pru0_dataram_phy_base;
        prussdrv.pruss_mdio_base =
            prussdrv.pru0_dataram_base + prussdrv.pruss_mdio_phy_base -
            prussdrv.pru0_dataram_phy_base;
    }
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
